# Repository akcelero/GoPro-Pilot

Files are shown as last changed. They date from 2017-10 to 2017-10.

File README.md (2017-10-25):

# GoPro-Pilot
Open source pilot for gopro hero 4 based on unofficial http api.

# READ IT BEFORE START

There is no connection between pin CH_PD and Vcc!
You need to put small wire to connect these two pins.

## Prepare board

TODO: describe how to prepare own PCB board

## Instalation

1. Put micropython into ESP<br />
`esptool.py --port /dev/ttyUSB0 --baud 460800 write_flash --flash_size=detect 0 LATEST_MICROPYTHON.bin`
2. Put credentials and main program<br />
`ampy --port /dev/ttyUSB0 put main.py /main.py`<br />
`ampy --port /dev/ttyUSB0 put credentials.config /credentials.config`
3. If pilot does not work, pls check debug output<br />
`screen /dev/ttyUSB0 115200`

## Sources:

1. List of instructions in api (congrats for this project)<br />
https://github.com/KonradIT/goprowifihack/blob/master/HERO4/WifiCommands.md
2. Micropython<br />
http://micropython.org/download#esp8266
3. Tutorial for micropython in ESP8266<br />
https://docs.micropython.org/en/latest/esp8266/esp8266/tutorial/intro.html

## License
Apache License 2.0v

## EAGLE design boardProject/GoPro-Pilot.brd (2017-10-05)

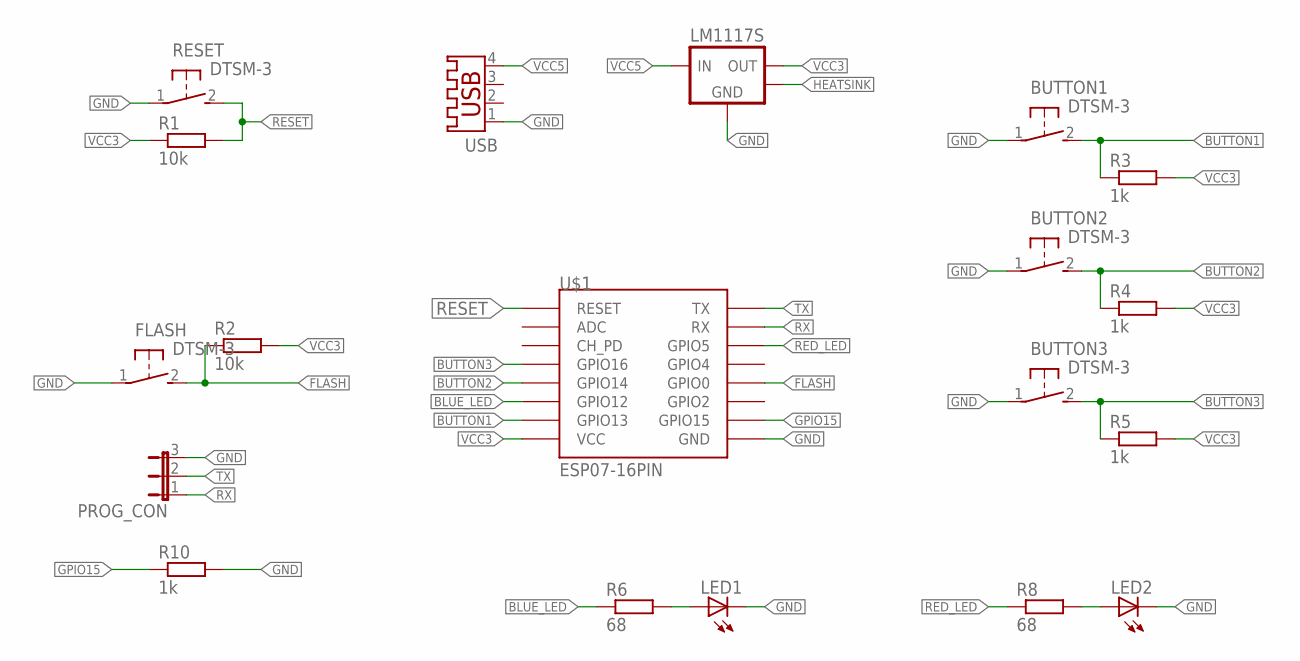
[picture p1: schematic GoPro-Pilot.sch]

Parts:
BUTTON1, BUTTON2, BUTTON3: DTSM-3
FLASH: DTSM-3
LED1, LED2: LEDSML0805; SML0805
LM1117S: LM1117-SOT223; SOT-223-3
PROG_CON: JP2E; JP2
R1, R2: 10k; R1005
R3, R4, R5, R10: 1k; R1005
R6, R8: 68; R1005
RESET: DTSM-3
U$1: ESP07-16PIN
USB: USB-A003

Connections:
BLUE_LED: R6.1, U$1.GPIO12
BUTTON1: BUTTON1.2, R3.1, U$1.GPIO13
BUTTON2: BUTTON2.2, R4.1, U$1.GPIO14
BUTTON3: BUTTON3.2, R5.1, U$1.GPIO16
FLASH: FLASH.2, R2.1, U$1.GPIO0
GND: BUTTON1.1, BUTTON2.1, BUTTON3.1, FLASH.1, LED1.C, LED2.C, LM1117S.1 (GND), PROG_CON.3, R10.2, RESET.1, U$1.GND, USB.1
GPIO15: R10.1, U$1.GPIO15
HEATSINK: LM1117S.4 (HEATSINK)
unnamed: LED2.A, R8.2
unnamed: LED1.A, R6.2
RED_LED: R8.1, U$1.GPIO4 (GPIO5)
RESET: R1.2, RESET.2, U$1.REST (RESET)
RX: PROG_CON.1, U$1.RX
TX: PROG_CON.2, U$1.TX
VCC3: LM1117S.2 (VOUT), R1.1, R2.2, R3.2, R4.2, R5.2, U$1.VCC
VCC5: LM1117S.3 (VIN), USB.4

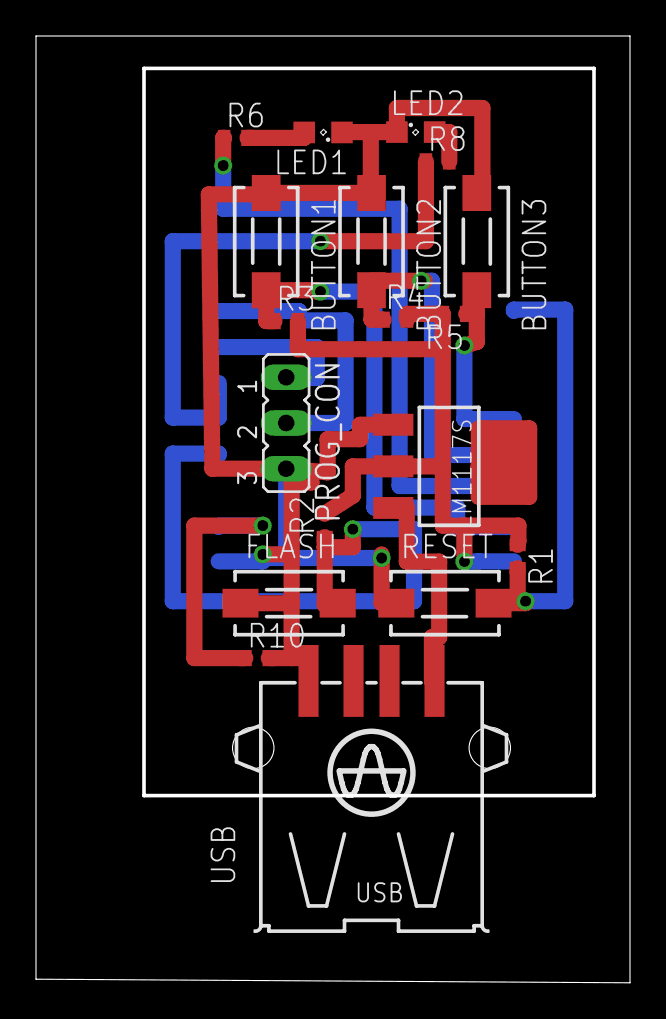
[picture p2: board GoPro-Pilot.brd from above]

Board: 2 copper layers, 33.0 x 52.6 mm, 19 parts (1 on the bottom side), 15 nets.

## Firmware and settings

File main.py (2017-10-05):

import network
import socket
import json
import sys
from machine import Pin
from time import sleep

network.WLAN(network.AP_IF).active(False)
network.WLAN(network.STA_IF).active(False)

try:
    with open('credentials.config') as f:
        credentials = [line.replace('\n', '') for line in f.readlines()]
except:
    print('Can not open file with credentials')
    raise

if len(credentials) != 2:
    print('Wrong struct of credentials file, check example')
    raise Error()

essid = credentials[0]
password = credentials[1]

goproIP = '10.5.5.9'

shutterPath = '/gp/gpControl/command/shutter?p=1'
stopPath = '/gp/gpControl/command/shutter?p=0'
photoMode = '/gp/gpControl/command/mode?p=1'
videoMode = '/gp/gpControl/command/mode?p=0'
locateOn = '/gp/gpControl/command/system/locate?p=1'
locateOff = '/gp/gpControl/command/system/locate?p=0'
statusPath = '/gp/gpControl/status'

blue_led = Pin(12, Pin.OUT)
red_led = Pin(4, Pin.OUT)

button1 = Pin(13, Pin.IN)
button2 = Pin(14, Pin.IN)
button3 = Pin(16, Pin.IN)

blue_led.value(0)
red_led.value(0)


def action(path):
    soc = socket.socket()
    soc.connect((goproIP, 80))
    soc.send(
            b'GET ' + path + ' HTTP/1.0\r\nHost: ' + path + '\r\n\r\n'
    )
    data = soc.read()
    soc.close()
    return data


def toggle(pin):
    pin.value(not pin.value())


def turnOn(led):
    led.value(1)


def turnOff(led):
    led.value(0)


def button1Callback(trigger):
    turnOn(blue_led)
    action(photoMode)
    action(shutterPath)
    sleep(0.2)
    turnOff(blue_led)


def button2Callback(trigger):
    turnOn(blue_led)
    data = action(statusPath)
    capturing = json.loads(
        '{' + data.decode('utf-8').split('{', 1)[1].replace('\n', '')
    )['status']['8']
    if not capturing:
        action(videoMode)
    path = '/gp/gpControl/command/shutter?p=' + str(capturing ^ 1)
    action(path)
    turnOff(blue_led)


def button3Callback(trigger):
    turnOn(blue_led)
    data = action(statusPath)
    locate = json.loads(
        '{' + data.decode('utf-8').split('{', 1)[1].replace('\n', '')
    )['status']['45']
    path = '/gp/gpControl/command/system/locate?p=' + str(locate ^ 1)
    action(path)
    turnOff(blue_led)


# ------- Initialize connect with camera -----------

sta = network.WLAN(network.STA_IF)
sta.active(True)
sta.connect(essid, password)

# ---- Inform about trying connect with camera -----

while not sta.isconnected():
    toggle(red_led)
    sleep(0.5)
turnOff(red_led)

# ------- Inform about succesful connection ---------

for i in range(8):
    toggle(blue_led)
    sleep(0.2)

# -------- Setup interrupts on buttons pins ----------

button1.irq(trigger=Pin.IRQ_FALLING, handler=button1Callback)
button2.irq(trigger=Pin.IRQ_FALLING, handler=button2Callback)
# GPIO16 has no IRQ function
# button3.irq(trigger=Pin.IRQ_FALLING, handler=button2Callback)

# Simulate callback at falling edge at button nr 3
prevStatusButton3 = button3.value()
while True:
    if prevStatusButton3 == 0 and not (prevStatusButton3 == button3.value()):
        button3Callback(button3)
    prevStatusButton3 = button3.value()
    sleep(0.2)
